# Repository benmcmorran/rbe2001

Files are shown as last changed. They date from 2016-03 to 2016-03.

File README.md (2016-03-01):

# RBE 2001 C16 Final Project
Nuclear reactor refueling challenge for WPI's RBE 2001

Current robot code is in the testRobott directory. See inline comments for more code documentation.

Full STLs and DXFs for 3D printing and laser cutting your own copy of our robot are in the CAD directory.

Open Source Hardware

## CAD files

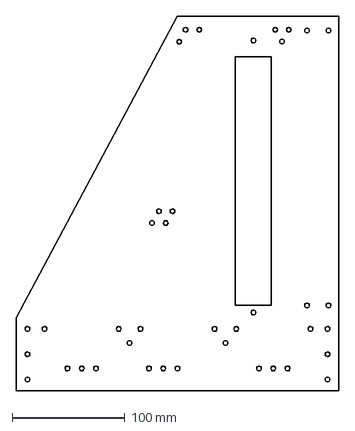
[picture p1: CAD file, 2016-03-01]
CAD/main_panel.dxf
286.2 x 332.4 mm

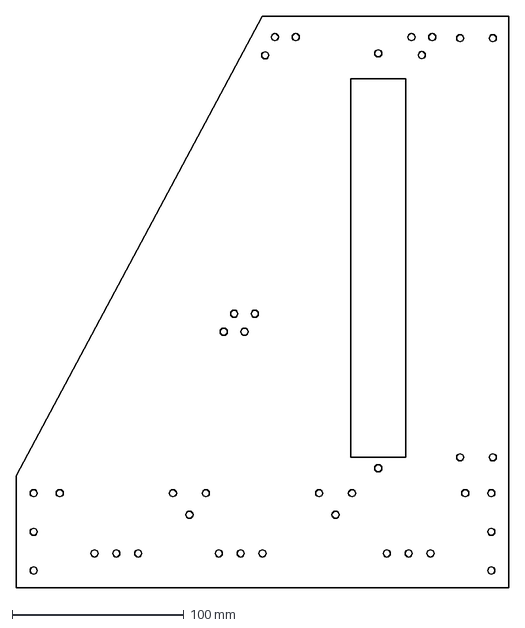
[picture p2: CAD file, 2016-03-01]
CAD/main_panelv2.dxf
286.2 x 332.4 mm

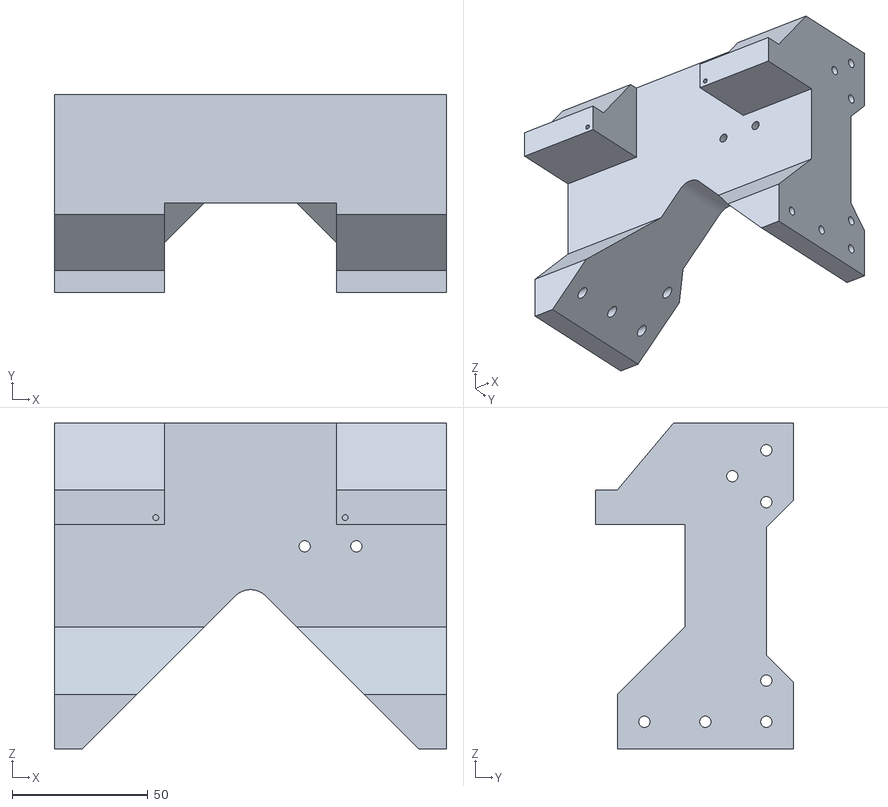
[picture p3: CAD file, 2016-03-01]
CAD/zrarmsby_main_block.stl
144.6 x 73.0 x 120.2

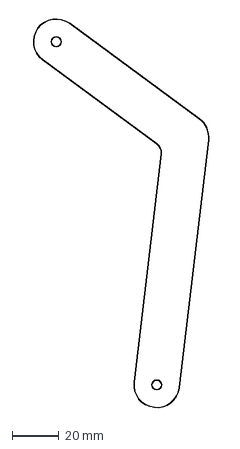
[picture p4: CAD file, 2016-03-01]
CAD/bar.dxf
76.2 x 167.4 mm

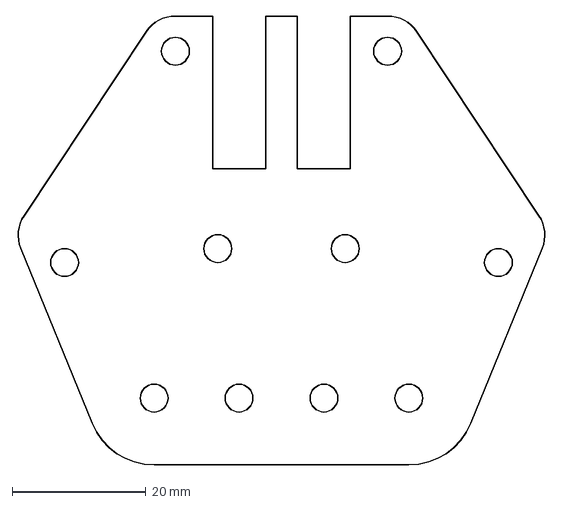
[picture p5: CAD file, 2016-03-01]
CAD/roller.dxf
79.3 x 67.2 mm

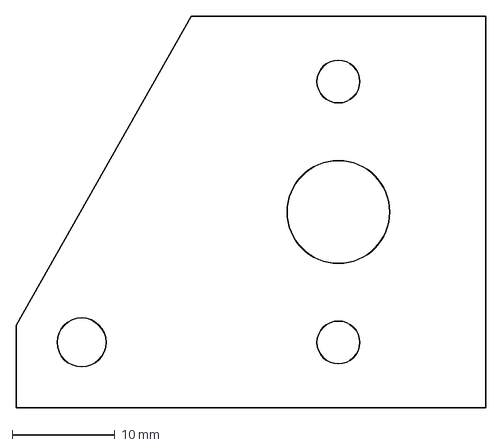
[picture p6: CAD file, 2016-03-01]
CAD/slider_adapt.dxf
45.7 x 38.1 mm

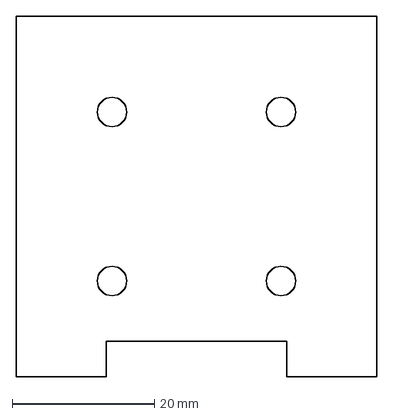
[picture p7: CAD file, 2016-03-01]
CAD/testv2.dxf
50.8 x 50.8 mm

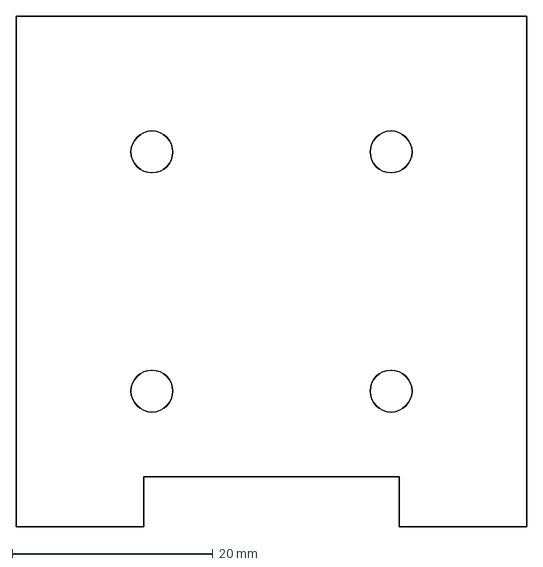
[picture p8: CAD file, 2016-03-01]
CAD/test.dxf
50.8 x 50.8 mm

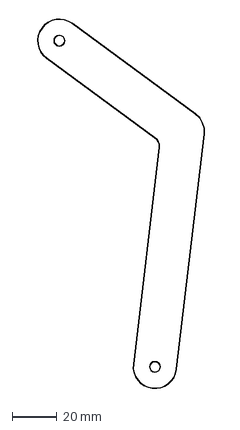
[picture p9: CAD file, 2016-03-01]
CAD/bar2.dxf
76.2 x 167.4 mm

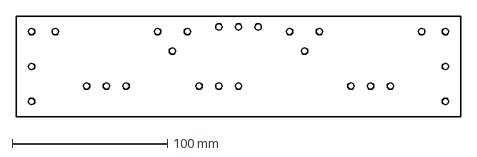
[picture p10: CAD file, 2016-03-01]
CAD/side_panel.dxf
286.2 x 65.0 mm

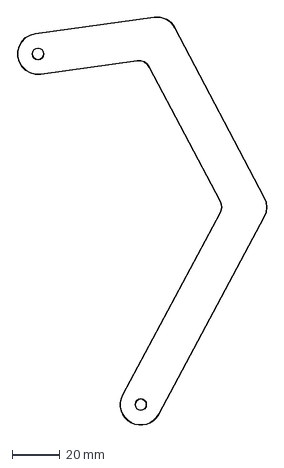
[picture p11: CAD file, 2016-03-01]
CAD/arm.dxf
104.8 x 171.7 mm

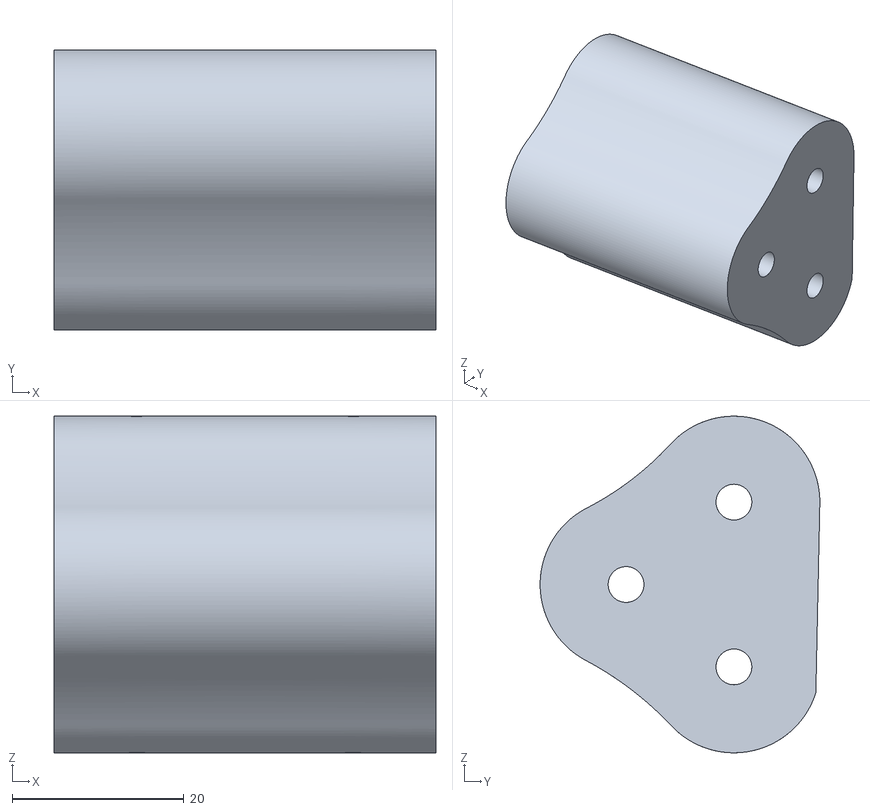
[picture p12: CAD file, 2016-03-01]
CAD/zrarmsby_drive_space_2.stl
44.5 x 32.6 x 39.2

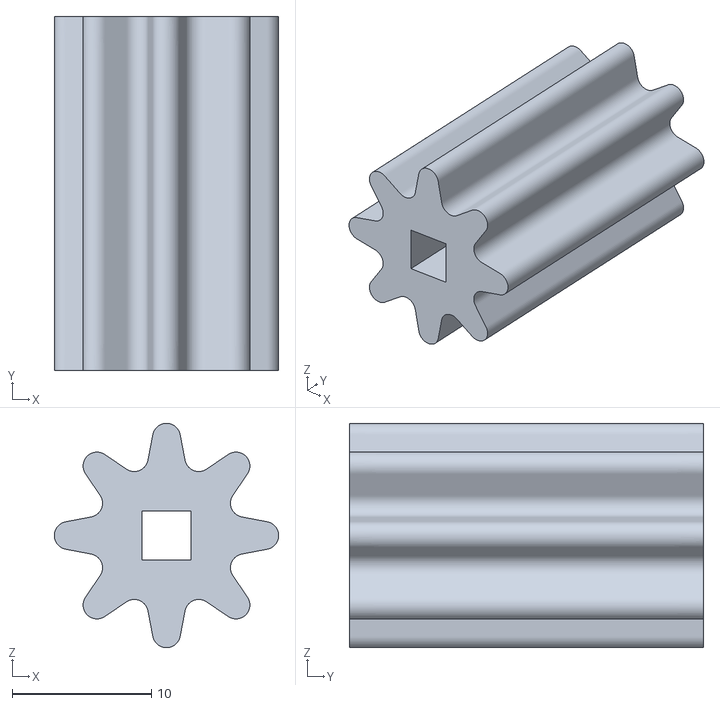
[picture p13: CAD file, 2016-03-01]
CAD/zrarmsby_roller_insert_2001_v3.stl
16.1 x 25.4 x 16.1

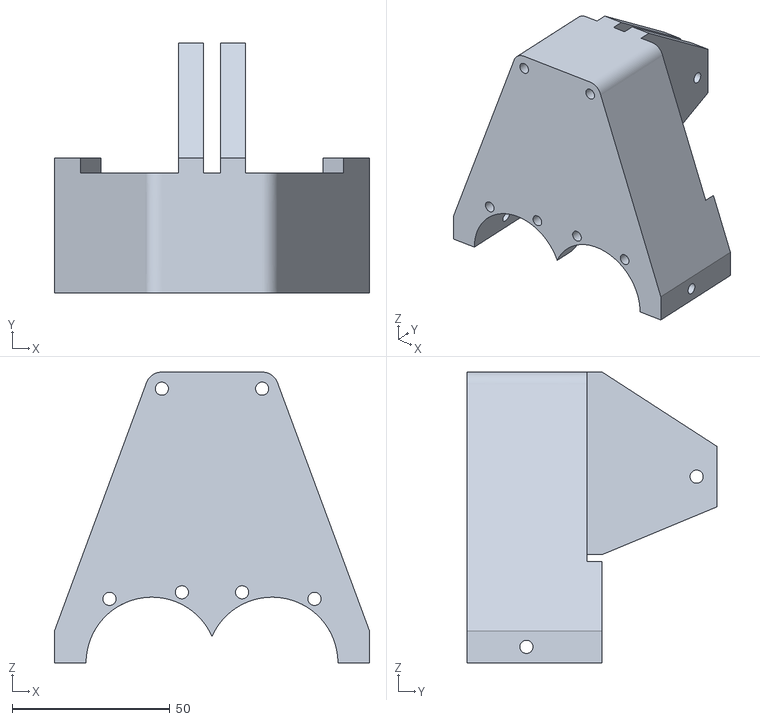
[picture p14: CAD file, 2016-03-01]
CAD/zrarmsby_intake.stl
99.7 x 79.3 x 92.1

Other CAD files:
CAD/zrarmsby_drive_space_3.stl
CAD/zrarmsby_roller_insert_2001.stl
CAD/zrarmsby_roller_2001_v2.stl
CAD/zrarmsby_drive_space_1.stl
CAD/top_plate.dxf
CAD/zrarmsby_drive_space_4.stl
CAD/zrarmsby_electonics_holder_spacer.stl
CAD/zrarmsby_endstop.stl
CAD/zrarmsby_endstop_mirror.stl
CAD/zrarmsby_roller_2001.stl
CAD/zrarmsby_roller_insert_2001_v2.stl
CAD/zrarmsby_rsl_mount.stl

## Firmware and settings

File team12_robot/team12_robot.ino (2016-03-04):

#include <TimerThree.h>
#include <TimerOne.h>
#include "Robott.h"
#include "song_tone.h"
#include <BluetoothMaster.h>
#include <ReactorProtocol.h>
#include <Servo.h>
#include <Encoder.h>
#include <PID_v1.h>

Robott R(12);

void setup() {
  pinMode(14,INPUT_PULLUP); //pull up one of the bluetooth pins
  pinMode(15,INPUT_PULLUP); //pull up one of the bluetooth pins
  Serial.begin(115200);
  Serial3.begin(115200);
  Timer1.initialize(2000000); //let timer1 generate an interrupt every 2 seconds
  Timer1.attachInterrupt(sendHB_ISR); //attach timer1 interrupt to sendHB_ISR
  Timer3.initialize(1000000); //let timer3 generate an interrupt every second
  Timer3.attachInterrupt(sendAlert_ISR); //attach timer3 interrupt to sendAlert_ISR
  R.initialize();
  R.main();
}

void loop() {
  play_rtttl(song);
}

void sendHB_ISR(){
  R.setIsHB(true); //set the send hearbeat flag to true
}
void sendAlert_ISR(){
  digitalWrite(alertLED,LOW); //turn off the physical alert LED
  R.isAlert=true; //set the send hearbeat flag to true
}

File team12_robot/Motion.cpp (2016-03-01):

#include "Motion.h"

// Define pins for bumpers and motors
#define FRONT_BUMPER_PIN 25

#define ARM_LEFT_TOP_BUMPER_PIN 27
#define ARM_LEFT_BOTTOM_BUMPER_PIN 29
#define ARM_RIGHT_TOP_BUMPER_PIN 26
#define ARM_RIGHT_BOTTOM_BUMPER_PIN 28

#define ARM_MOTOR_LEFT_PIN 8
#define ARM_MOTOR_RIGHT_PIN 9
#define ARM_MOTOR_INTAKE_PIN 7

/*
 * Constructs a new Motion. initialize() must be called before using
 * the Motion to attach motors and set pin modes.
 */
Motion::Motion() :
  sensor(lineSensorPins),
  leftEnc(19, 20),
  rightEnc(18, 3),
  setpoint(0), input(0), output(0),
  pid(&input, &output, &setpoint, 10, 0, 2, DIRECT) {
}

/*
 * Attaches motors and sets pin modes. This is a separate function
 * because the Arduino libraries must initialize before attaching,
 * so putting this functionality in the constructor would cause it
 * to run too early.
 */
void Motion::initialize() {
  left.attach(10);
  right.attach(11);
  pinMode(FRONT_BUMPER_PIN, INPUT_PULLUP);
  pid.SetOutputLimits(-80, 80);

  pinMode(ARM_LEFT_TOP_BUMPER_PIN, INPUT_PULLUP);
  pinMode(ARM_LEFT_BOTTOM_BUMPER_PIN, INPUT_PULLUP);
  pinMode(ARM_RIGHT_TOP_BUMPER_PIN, INPUT_PULLUP);
  pinMode(ARM_RIGHT_BOTTOM_BUMPER_PIN, INPUT_PULLUP);

  armLeft.attach(ARM_MOTOR_LEFT_PIN);
  armRight.attach(ARM_MOTOR_RIGHT_PIN);
  armIntake.attach(ARM_MOTOR_INTAKE_PIN);
}

/*
 * Returns true if the current state has finished processing.
 */
bool Motion::isDone() {
  return done;
}

/*
 * Starts a 90 degree right turn.
 */
void Motion::turnRight() {
  state = TURN_RIGHT;
  setupEncoderMotion(320, 75, -150, 105);
}

/*
 * Starts a 90 degree left turn.
 */
void Motion::turnLeft() {
  state = TURN_LEFT;
  setupEncoderMotion(-150, 105, 320, 75);
}

/*
 * Spins in place 180 degrees.
 */
void Motion::turn180() {
  state = TURN_180;
  setupEncoderMotion(520, 80, -520, 107);
}

/*
 * Backs up a few inches to get away from the fuel rods.
 */
void Motion::reverse() {
  state = TURN_180;
  setupEncoderMotion(-230, 105, -230, 108);
}

/*
 * Line follows while counting intersections. Stops when count
 * intersections have been crossed.
 */
void Motion::trackToIntersection(int count) {
  state = TRACK_TO_INTERSECTION;
  done = false;
  isInIntersection = false;
  intersectionCount = 0;
  intersectionTarget = count;
}

/*
 * Line follows until the front bumper is pressed. The motors continue
 * to be driven for 1 second after contact to ensure a snug fit.
 */
void Motion::trackToBump() {
  state = TRACK_TO_BUMP;
  done = false;
  hitFrontBump = false;
}

/*
 * Moves the arm to the down position.
 */
void Motion::armDown() {
  state = ARM_DOWN;
  hitLeft = hitRight = false;
  done = false;
}

/*
 * Moves the arm to the up position. The intake is spun out during the
 * motion if dispensingRod is true. This can help avoid pulling the fuel
 * rod back out of the reactor.
 */
void Motion::armUp(bool dispensingRod) {
  state = ARM_UP;
  hitLeft = hitRight = false;
  this->dispensingRod = dispensingRod;
  done = false;
}

/*
 * Spins the intake rollers in for a short while.
 */
void Motion::intakeIn() {
  state = INTAKE_IN;
  intakeStartTime = millis();
  done = false;
}

/*
 * Spins the intake rollers our for a short while.
 */
void Motion::intakeOut() {
  state = INTAKE_OUT;
  intakeStartTime = millis();
  done = false;
}

/*
 * Updates the robot's motion based on its current state and inputs. This
 * function should be called periodically. It is safe to continue calling
 * update after the motion has finished or after calling stop().
 */
void Motion::update() {
  if (done || isStopped) return;

  switch (state) {
    // All encoder states drive the same way
    case TURN_RIGHT:
    case TURN_LEFT:
    case TURN_180:
    case BACKWARDS:
      driveFromEncoder();
      break;
    // Line tracking states drive basically the same, but the end
    // condition is different.
    case TRACK_TO_INTERSECTION:
      if (intersectionCount == intersectionTarget) {
        left.write(90);
        right.write(90);
        done = true;
      } else {
        trackLine();
      }
      break;
    case TRACK_TO_BUMP:
      if (hitFrontBump && millis() - frontBumpTime > 1000) {
        left.write(90);
        right.write(90);
        done = true;
      } else if (!hitFrontBump && digitalRead(FRONT_BUMPER_PIN) == LOW) {
        hitFrontBump = true;
        frontBumpTime = millis();
      } else {
        trackLine();
      }
      break;
    // Arm states drive the same except for pins and direction
    case ARM_DOWN:
      moveArm(ARM_LEFT_BOTTOM_BUMPER_PIN, ARM_RIGHT_BOTTOM_BUMPER_PIN, 83);
      break;
    case ARM_UP:
      moveArm(ARM_LEFT_TOP_BUMPER_PIN, ARM_RIGHT_TOP_BUMPER_PIN, 105);
      if (dispensingRod && !done) armIntake.write(80);
      else armIntake.write(90);
      break;
    // Intake states just drive at different speeds
    case INTAKE_IN:
      driveIntake(110);
      break;
    case INTAKE_OUT:
      driveIntake(80);
      break;
  }
} 

/*
 * Temporarily stops the robot's motion. It can be resumed with resume().
 */
void Motion::stop() {
  isStopped = true;
  left.write(90);
  right.write(90);
  armLeft.write(90);
  armRight.write(90);
  armIntake.write(90);
}

/*
 * Resumes the robot's motion after calling stop().
 */
void Motion::resume() {
  isStopped = false;
}

/*
 * Configures internal state for an encoder motion.
 */
void Motion::setupEncoderMotion(int leftLimit, int leftSpeed, int rightLimit, int rightSpeed) {
  done = false;
  pid.SetMode(MANUAL);
  this->leftLimit = leftLimit;
  this->rightLimit = rightLimit;
  this->leftSpeed = leftSpeed;
  this->rightSpeed = rightSpeed;
  resetEncoders();
}

/*
 * Sets both encoders back to zero.
 */
void Motion::resetEncoders() {
  leftEnc.write(0);
  rightEnc.write(0);
}

/*
 * Drives the wheels based on values set by setupEncoderMotion(). done
 * is true when both left and right have met their target.
 */
void Motion::driveFromEncoder() {
  // Check if we have met each target, accounting for the direction of
  // the desired rotation
  bool driveLeft = leftLimit < 0 ? leftEnc.read() >= leftLimit : leftEnc.read() <= leftLimit;
  bool driveRight = rightLimit < 0 ? rightEnc.read() >= rightLimit : rightEnc.read() <= rightLimit;

  // Spin the motor at the desired speed if there's still distance left
  left.write(driveLeft ? leftSpeed : 90);
  right.write(driveRight ? rightSpeed : 90);

  // Check if we're done yet
  done = !driveLeft & !driveRight;
}
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

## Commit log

2016-02-20 Speed control and motor class
2016-02-23 Update
    it perfectly worked ~\(≧▽≦)/~
2016-02-24 Encoder turns and backing
2016-02-26 Add arm control to Motion
2016-02-28 SendAlert and LED alerting are done
2016-03-01 more CAD
    [arm.dxf, bar.dxf, bar2.dxf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]
